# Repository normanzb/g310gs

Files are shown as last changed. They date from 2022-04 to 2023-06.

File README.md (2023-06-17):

# Norm's G310GS mods

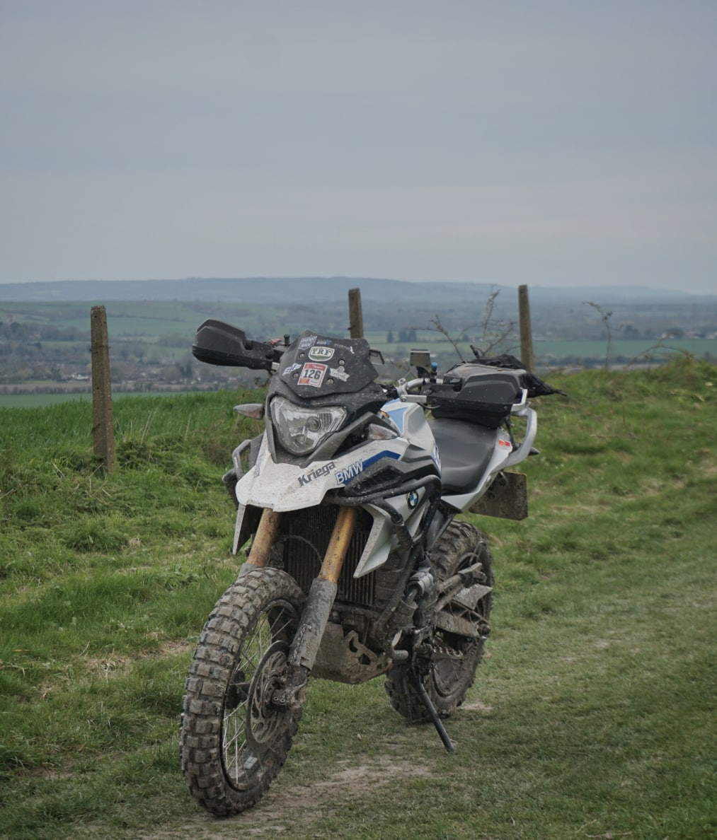
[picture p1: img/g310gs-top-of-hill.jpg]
Norm's G310GS with mods


Second hand G310GS on the market is a lot more affordable and more versatile then a brand new Honda CRF300L, however, when it comes to greenlaning there are improvements to be done to make the baby GS more prepared in the technical terrains.

Here you will find the mods that I made while improving my own g310gs to make it more capable off road.

## Disclaimer: Use at your own discretion

Bike parts can be changed overtime, they can also completely different in shape when it is sold in different region. The part in this repo might not fit straight to your bike.
Authors of this repo do not responsible for any damage caused by the mods made to your property, vehicle or health.

## Mods

--> __[TLDR, straight to the STL files!](https://github.com/normanzb/g310gs/blob/master/release/23_03_24)__ <--

See [changelog](./DocChangelog.md)

### Removing the front mudguard

The baby GS comes with the classic GS beaky look with a lower front mud guard that provides a better high speed riding experience. However in very muddy condition the lower front mud guard can clog up with muds and stop the front wheel from spinning. This makes the bike unrideable until the clearance is re-gained by removing the front mud guard. 

Below parts help you to remove the front mud guard while still providing protection for the vulnerable parts:

* [Radiator guard](./DocRadiatorGuard.md)
* [Fork guards](./DocForkGuards.md)

### Better stand up posture

* [Brake riser](./DocBrakeRiser.md)

## Please Help!

Designing and testing motorbike mods are time consuming and costly, I had to print out the parts, install them on my bike, identify the problems and re-do the design and printing. Each time just the printing along cost me somewhere around £30 to £180. Also in the process I was risking breaking the parts on my bike.

While I am happy to pay for my own habit, if you find this project helpful, please consider donate a little to keep the project going.

__I accept ETH on:__

0xC506739D39cBf1D94E2510bfcA64Cb6015F4Bb1B

__Buy me a drink on paypal:__

https://paypal.me/norx

## Acknowleges

Thanks for user `rcat` from g310rforum.com for the helps and feedbacks.

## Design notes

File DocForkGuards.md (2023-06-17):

# Fork Guards

The latest fork guards are made to fit the rally raid level 2 suspension kit (2mm increase on the total length on the fork). they should work on the stock forks but might be a bit longer then what you wanted.

## Caveats

* For the best result, please use SLS or MDF printer with PA12 Nylon material. 
* For the safety reason, please do check the sign of wear for the brake cable that run through the hoop on the left fork guard.

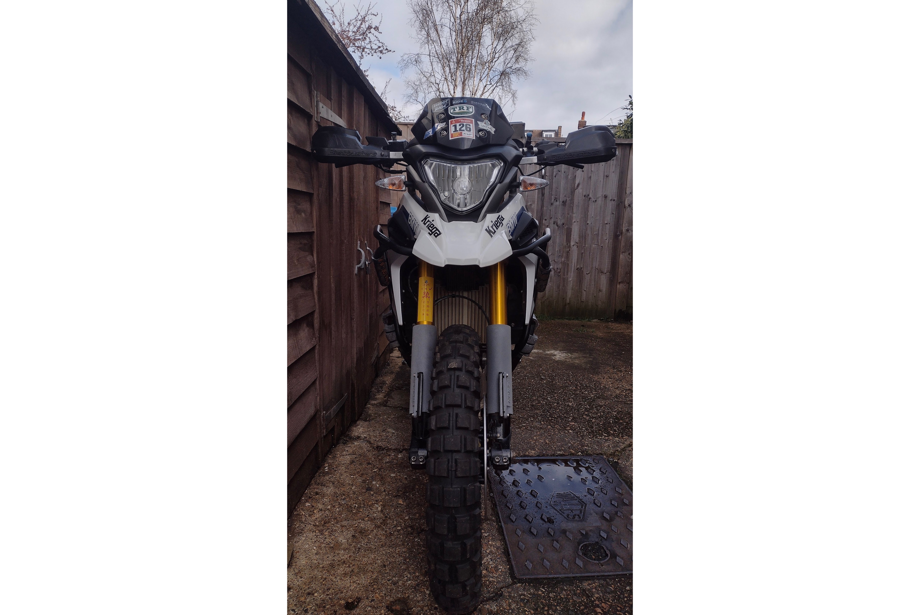
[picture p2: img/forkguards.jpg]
norx fork guards


[Click here for older version that fits stock fork better](https://github.com/normanzb/g310gs/blob/master/release/23_06_17/)

## Rally Raid Lvl2 Right Front Fork Guard

* __Project status:__ Fully Tested
* [STL file preview and download](https://github.com/normanzb/g310gs/blob/master/release/23_03_20/mudguard_alt_right_rally_raid_lvl2.stl)

## Rally Raid Lvl2 Left Front Fork Guard

* __Project status:__ Fully Tested
* [STL file preview and download](https://github.com/normanzb/g310gs/blob/master/release/23_06_17/mudguard_alt_left_rally_raid_lvl2.stl)

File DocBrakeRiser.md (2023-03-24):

# Brake riser

It comes with 2 variants: 15mm and 25mm. Both comes with holes that fits 3mm grub screws, so you can further micro adjusting the position by fitting longer or shorter grub screws.

To secure it to the original brake pedal, use 4 2mm wide zipties and route them through horizontal securing holes on the riser.

## Brake riser 15mm

* __Project status:__ Old version fully tested, ziptie version hasn't
* [STL file preview and download](https://github.com/normanzb/g310gs/blob/master/release/23_03_24/brake_riser_15mm_ziptie.stl)

15mm version works the best with sw motech footpegs in low position.

## Brake riser 25mm

* __Project status:__ Old version fully tested, ziptie version hasn't
* [STL file preview and download](https://github.com/normanzb/g310gs/blob/master/release/23_03_24/brake_riser_25mm_ziptie.stl)

25mm version works the best with fastway footpegs.

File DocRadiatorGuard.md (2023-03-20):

## Radiator Guard

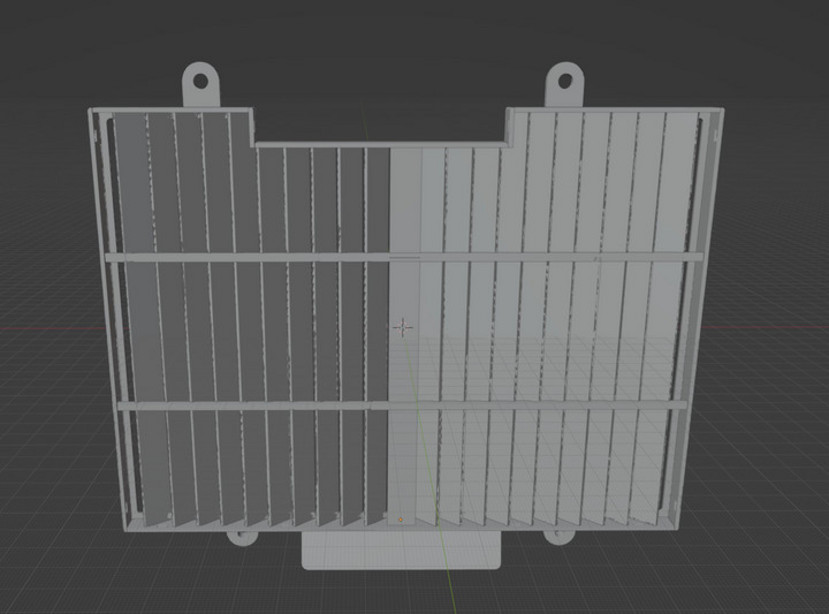
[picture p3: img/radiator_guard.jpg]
Radiator guard


* __Project status:__ Prototype Tested
* __Printing Caveat:__ Use heat resistent material
* [STL file preview and download](https://github.com/normanzb/g310gs/blob/master/release/23_03_20/radiator%20guard.stl)

What prevents most people front removing the front mud guard is the rocks or sand blasting from the front wheel can damage the radiator fins. And all the after market radiator guards you can buy are just a thin layer of metal that only protect against small rocks but still allowing the sand particles to go through.

If you look carefully, almost all the off road oriented bikes, including all the MX/enduro bikes and KTM 890 ADV and yamaha tenere 700, they all come equiped a stock radiator guard that consist of a series louvre blades. These blades not only protect against rocks but also sand blasting.

Below are few examples:

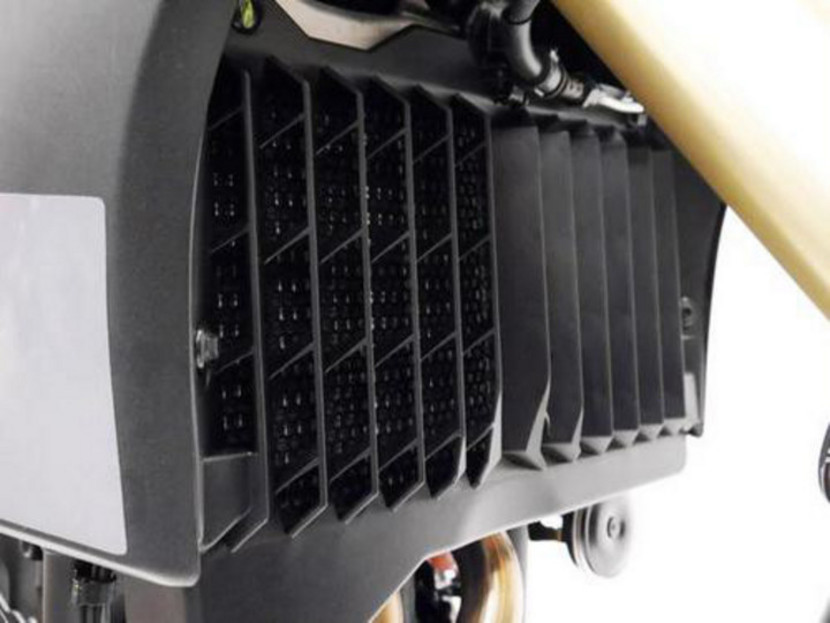
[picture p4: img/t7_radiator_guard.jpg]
Stock Radiator Guard on tenere 700


_Stock Radiator Guard on tenere 700_

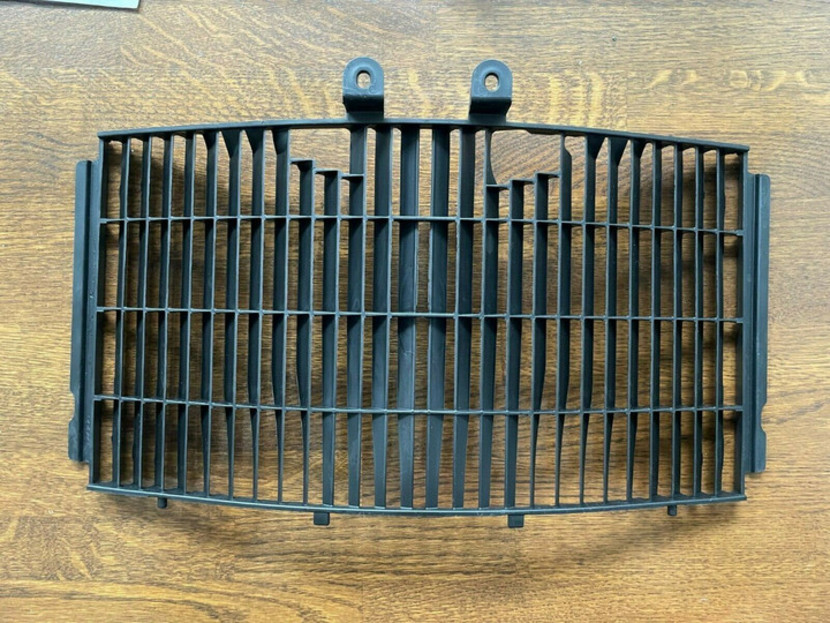
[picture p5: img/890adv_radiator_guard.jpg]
Stock Radiator Guard on KTM 890 adv


_Stock Radiator Guard on KTM 890 adv_

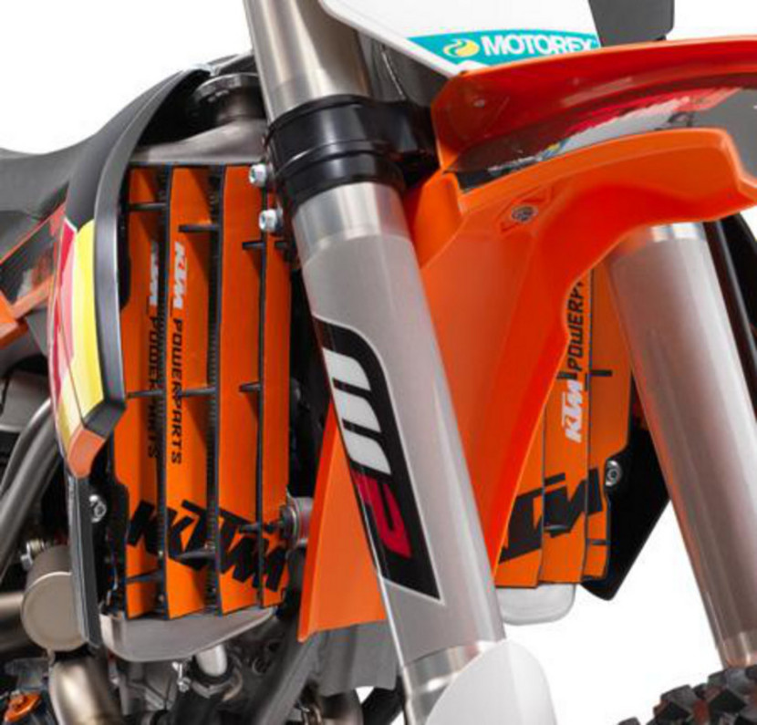
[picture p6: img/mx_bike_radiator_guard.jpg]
Almost all MX bikes have fitted with louvre blades


_Almost all MX bikes have fitted with louvre blades_

Our radiator guard tries to achieve the same by adding the louvre blades, you can also secure a piece of drain grill mesh on top of it with a ziptie to add some more protection against rocks.

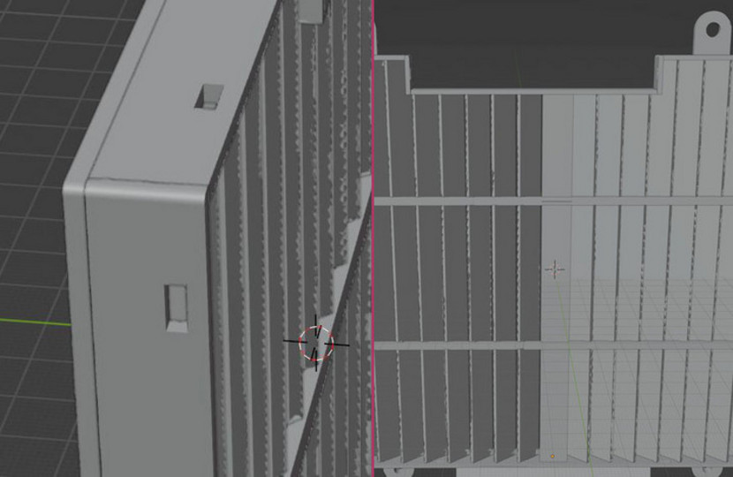
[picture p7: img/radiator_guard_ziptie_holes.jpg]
Radiator guard ziptie holes


_We added holes on the radiator guard so that you can secure a piece of drain grill mesh with a ziptie on it_

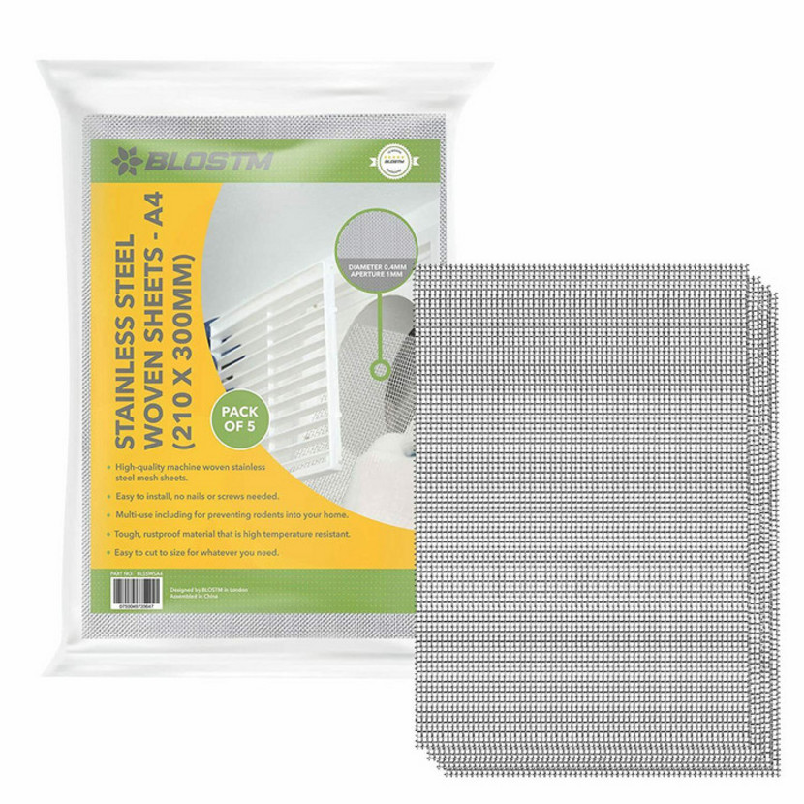
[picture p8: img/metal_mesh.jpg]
Metal mesh


_You can fit metal mesh from ebay to add some more protection_

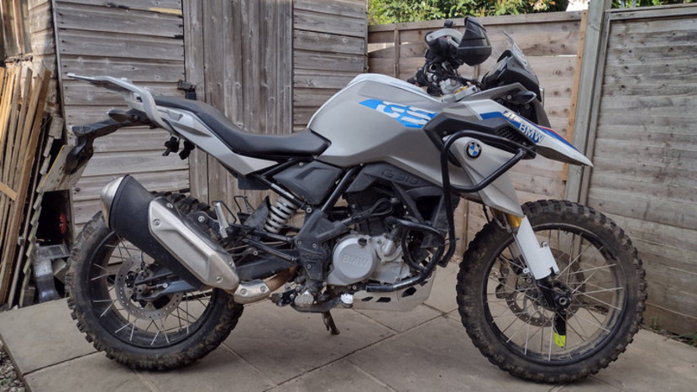
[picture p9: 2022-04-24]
img/g310gs_with_mods.jpg

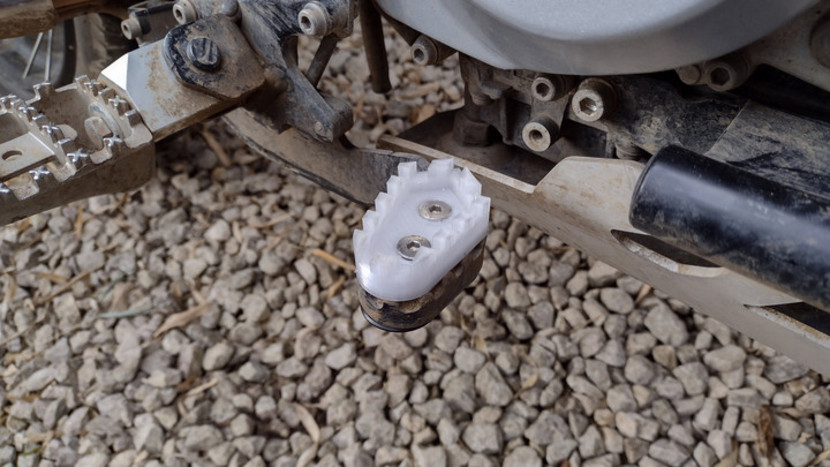
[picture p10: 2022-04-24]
img/brake_riser.jpg

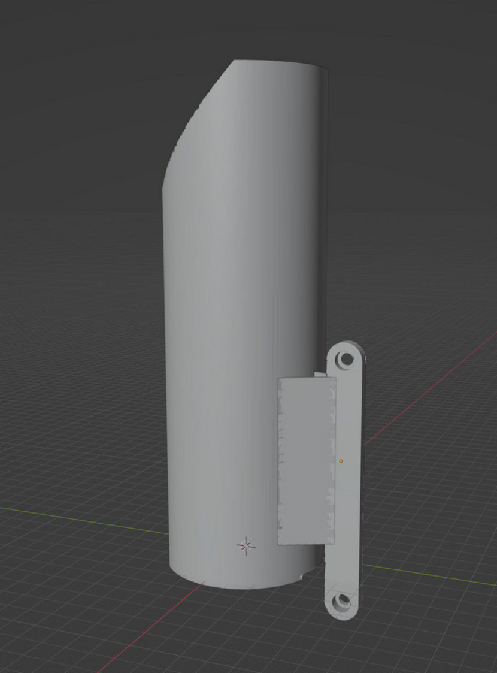
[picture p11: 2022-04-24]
img/mud_guard_right.jpg

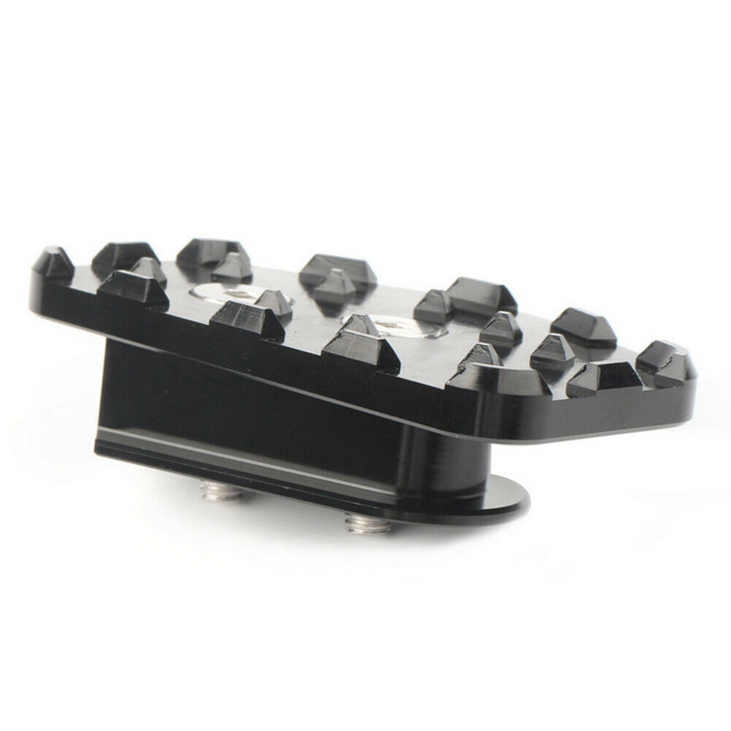
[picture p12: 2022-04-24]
img/ebay_brake_extension.jpg

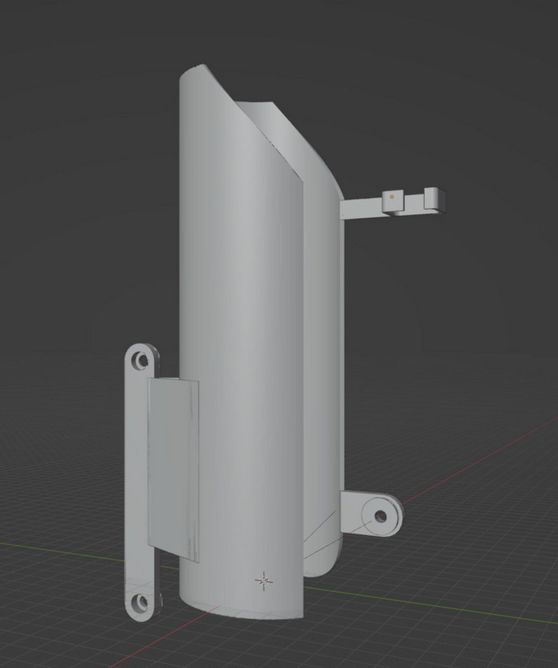
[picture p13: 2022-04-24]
img/mud_guard_left.jpg

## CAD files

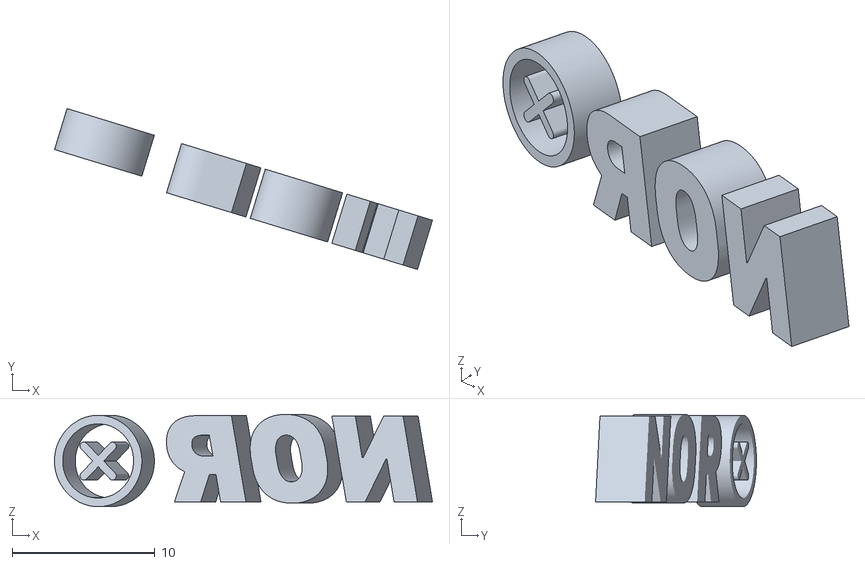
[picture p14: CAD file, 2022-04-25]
norx.stl
26.5 x 11.3 x 6.46

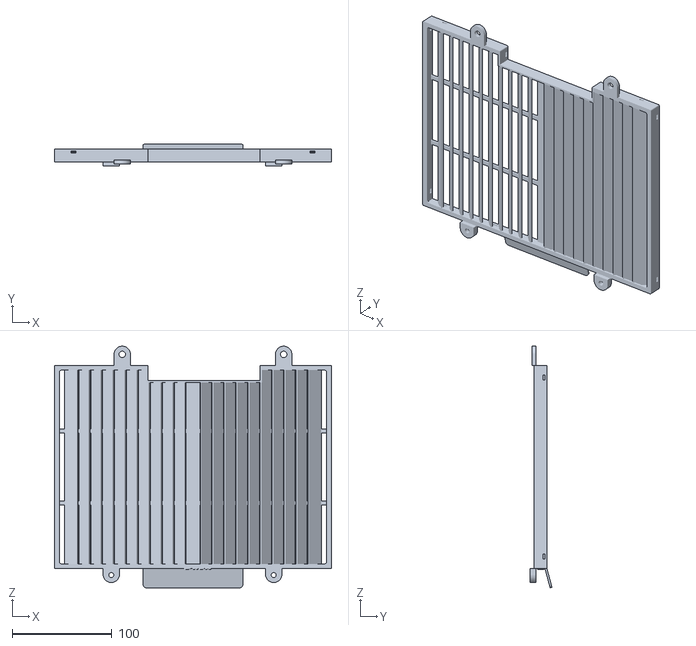
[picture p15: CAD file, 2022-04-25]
release/22_04_25/radiator guard.stl
278.0 x 22.1 x 242.5

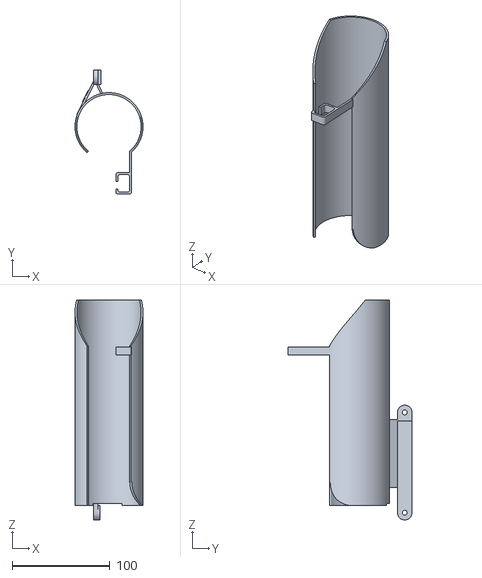
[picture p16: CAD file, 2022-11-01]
release/22_11_01/mudguard alt left.stl
69.6 x 127.0 x 225.0

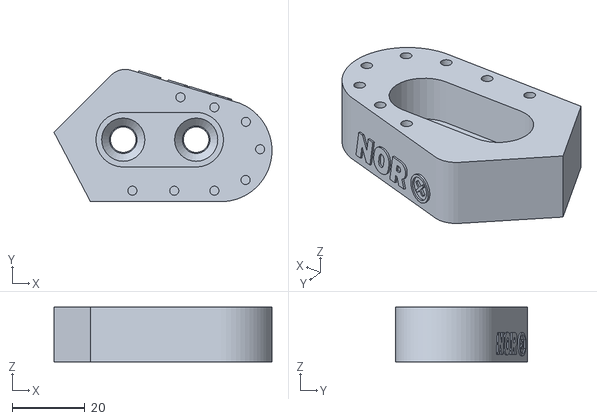
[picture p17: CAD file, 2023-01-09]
release/23_01_09/brake_riser.stl
59.8 x 36.3 x 15.0

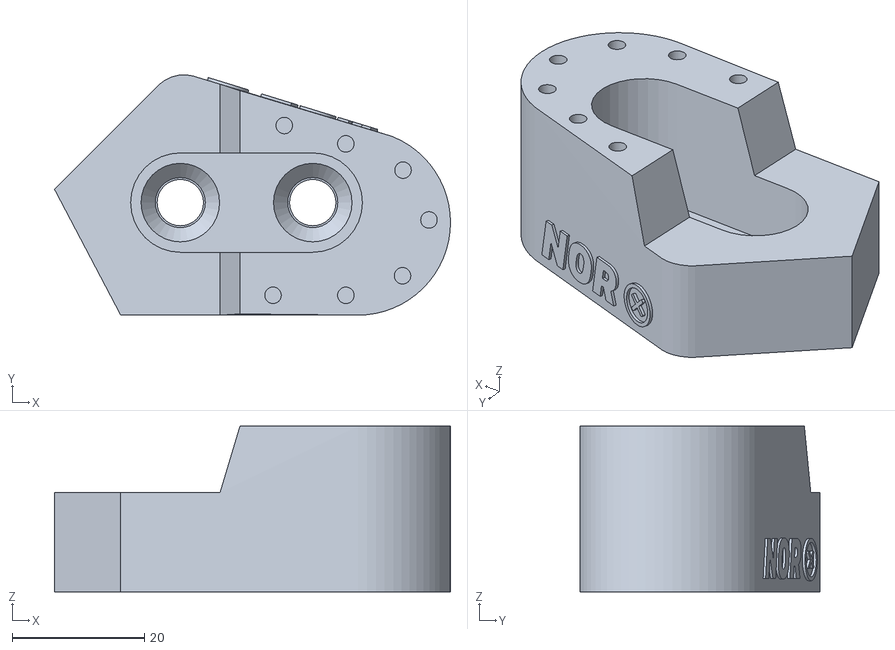
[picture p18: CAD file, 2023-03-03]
release/23_02_28/brake_riser_25mm.stl
59.8 x 36.3 x 25.0

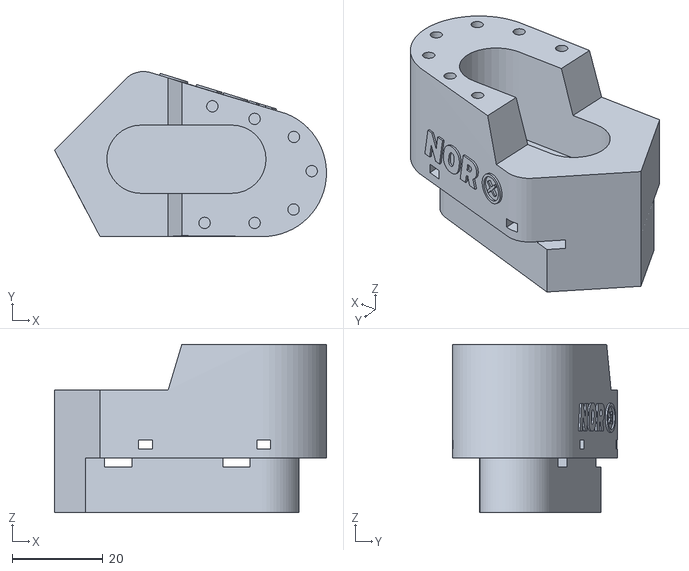
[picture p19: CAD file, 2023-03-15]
release/23_03_13/brake_riser_25mm_ziptie.stl
59.8 x 36.3 x 37.0

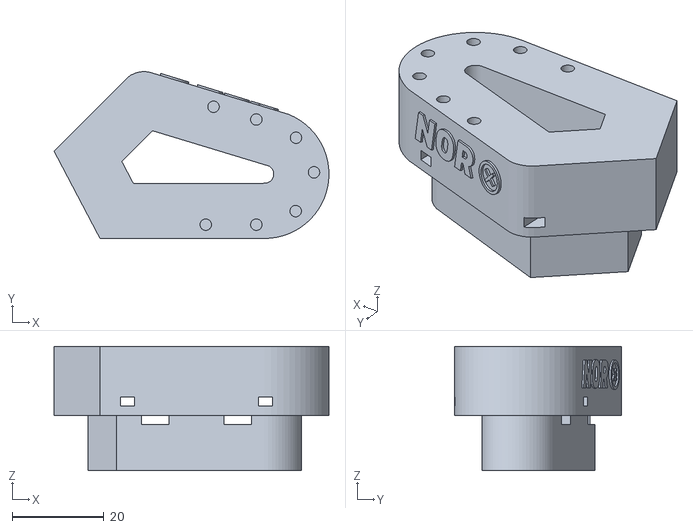
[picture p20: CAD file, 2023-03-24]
release/23_03_24/brake_riser_15mm_ziptie.stl
59.8 x 36.3 x 27.0

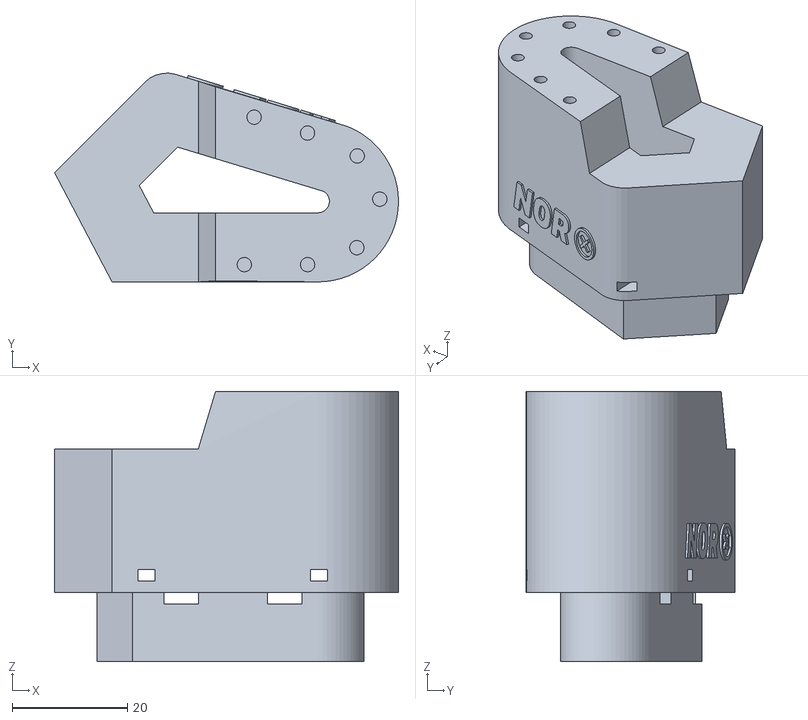
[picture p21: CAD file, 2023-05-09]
release/23_05_09/brake_riser_35mm_ziptie.stl
59.8 x 36.3 x 47.0

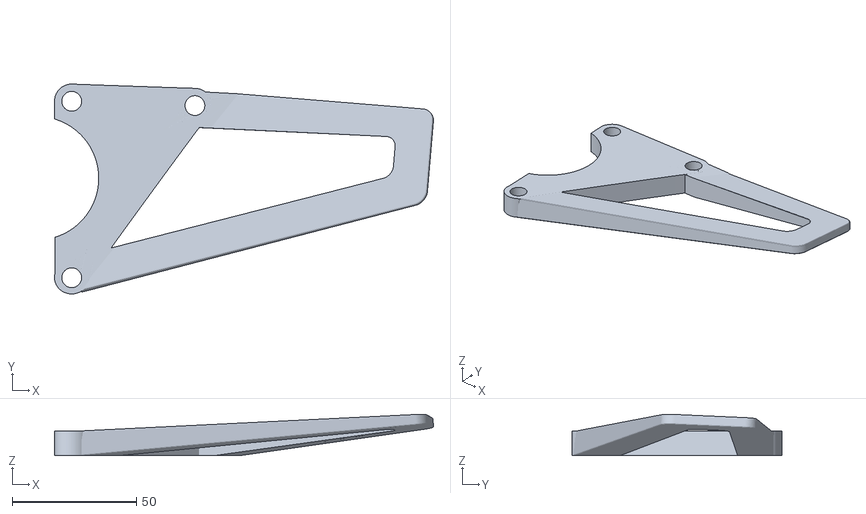
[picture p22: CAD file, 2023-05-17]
release/23_05_17/pillion_pegs_rack_replacement.stl
152.5 x 84.5 x 16.6

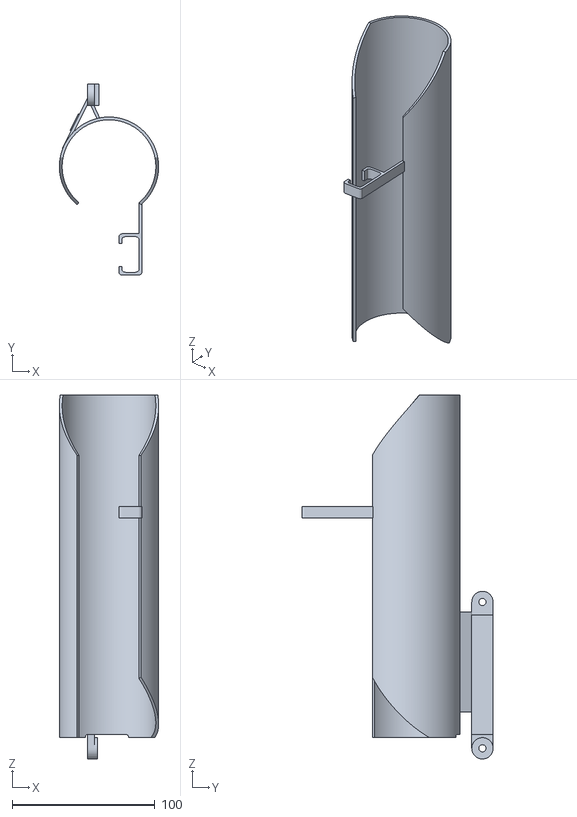
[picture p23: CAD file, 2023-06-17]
release/23_06_17/mudguard_alt_left_rally_raid_lvl2.stl
69.6 x 134.0 x 255.0

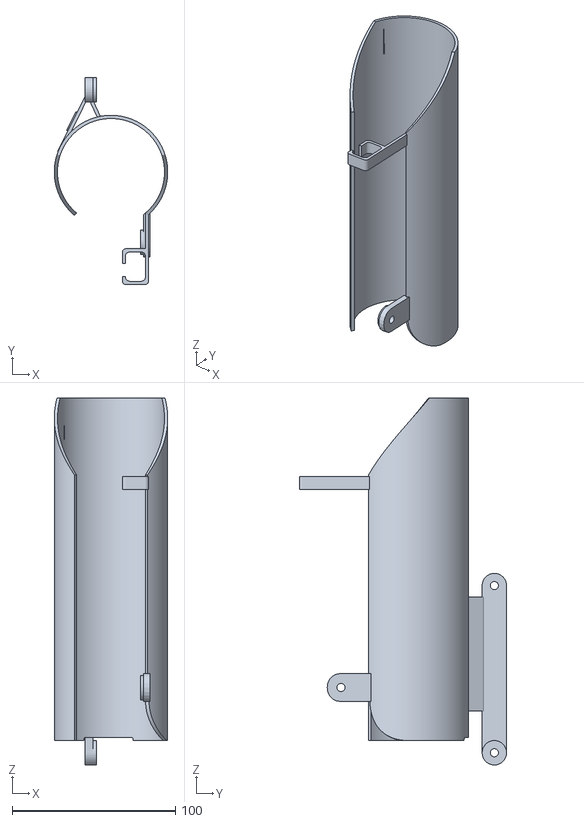
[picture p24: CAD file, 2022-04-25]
release/22_04_25/mudguard alt left.stl
69.6 x 127.0 x 225.0

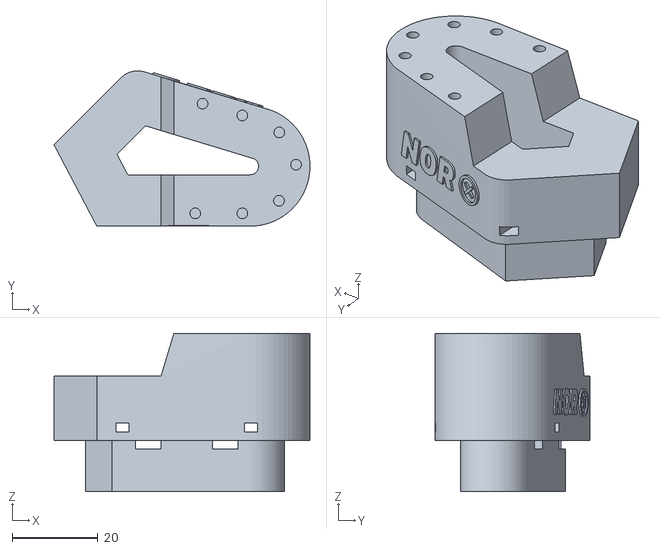
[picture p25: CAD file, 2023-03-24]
release/23_03_24/brake_riser_25mm_ziptie.stl
59.8 x 36.3 x 37.0

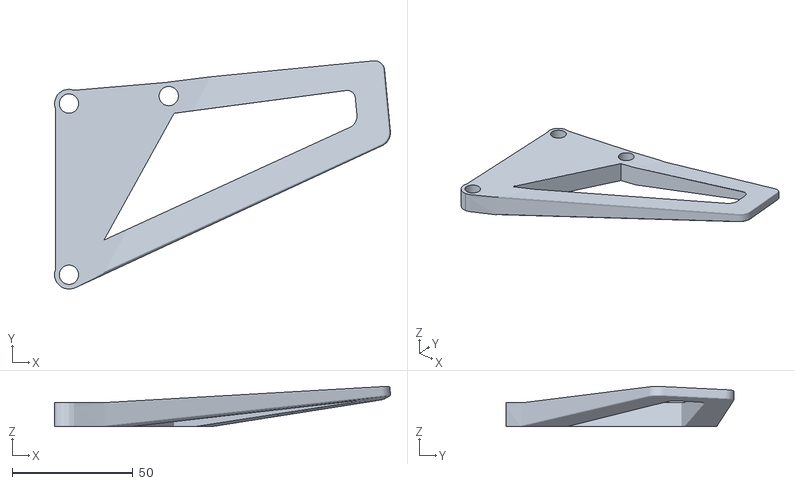
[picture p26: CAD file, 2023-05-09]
release/23_05_09/pillion_pegs_rack_replacement_left.stl
139.4 x 94.8 x 16.6

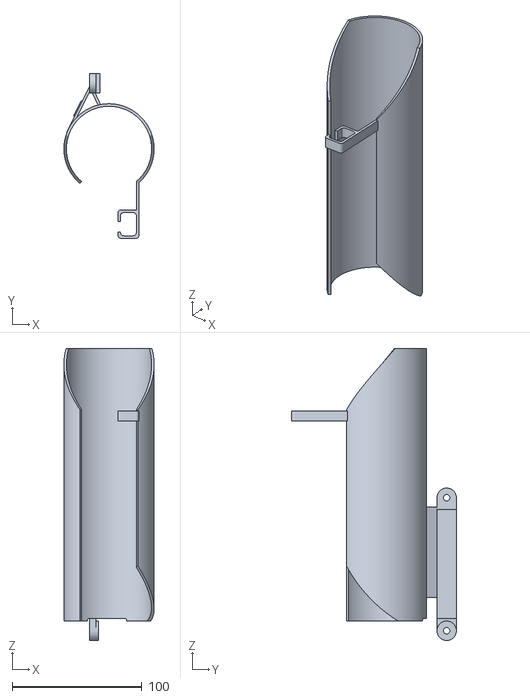
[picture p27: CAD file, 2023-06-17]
release/23_06_17/mudguard_alt_left.stl
69.6 x 127.0 x 225.0

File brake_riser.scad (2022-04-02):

// polygon([[0, 0], [135, 0], [8, 37],  [-10, 19]]);


union() {    
    polygon(
        [[0, 0], [36, 0], [41, 27],  [13, 35], [2, 31.5], [-10, 19]]
    );
    translate([35.5, 14, 0]) {
        circle(14);
    }
}



// rotate_extrude(convexity = 1)
// translate([2, 0, 0])
// circle(r = 1, $fn = 100);

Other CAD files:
release/22_04_25/mudguard alt right.stl
release/23_03_24/radiator guard.stl
release/23_06_17/mudguard alt right.stl
release/22_04_25/brake riser.stl
brake_riser_15mm.blend
brake_riser_25mm.blend
brake_riser_25mm_ziptie.blend
mudguard_alt_left.blend
mudguard_alt_left_rally_raid_lvl2.blend
mudguard_alt_right.blend
mudguard_alt_right_rally_raid_lvl2.blend
pillion_pegs_rack_replacement.blend
radiator guard.blend
release/21_12_01/mudguard alt left.stl
release/21_12_01/mudguard alt right.stl
release/21_12_01/radiator guard.stl
release/22_01_01/mudguard alt left.stl
release/22_01_01/mudguard alt right.stl
release/22_01_01/radiator guard.stl
release/22_04_02/brake riser.stl
release/22_04_02/mudguard alt left.stl
release/22_04_02/mudguard alt right.stl
release/22_04_24/brake riser.stl
release/22_04_24/mudguard alt left.stl
release/22_04_24/mudguard alt right.stl
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

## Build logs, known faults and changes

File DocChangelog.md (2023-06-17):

## 23-06-17

1. based on feedback from user `rcat` from g310rforum, moved 1mm inward on the front bracket for the left fork guard.
2. based on feedback from user `rcat` from g310rforum, increased the size of cut off for abs rack.

## 23-03-24

1. add a bigger vertical hollow to the brake riser so we can route ziptie through the hollow to better secure the brake riser

## 23-03-22

1. fixed brake riser geometry issue that prevent it from be inserted into brake pedal.
2. added a hole to brake riser for water escape.
3. readjust ziptie strap locations due to issues above.

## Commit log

2022-02-16 upload belnder files\
    [mudguard alt left.blend, mudguard alt left.stl, mudguard alt right.blend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]
2022-04-02 add brake riser
    [brake riser.blend, brake riser.scad, brake riser.stl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]
2022-04-02 brake riser
    [mudguard alt left.stl]
2022-04-24 updated riser file
    [brake riser.stl]
2022-04-24 brake riser should be final now
    [brake riser.blend]
2022-04-24 adjust mudguard right because too tight on the right side
    [mudguard alt right.blend]
2022-04-24 enlarge mudguard alt cable hook for stronger and better protection
    [mudguard alt left.blend]
2022-04-24 move release files into release folder
    [brake riser.stl, mudguard alt left.stl, mudguard alt right.stl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]
2022-04-24 rename release folder for easier sorting
    [brake riser.stl, mudguard alt left.stl, mudguard alt right.stl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]
2022-04-24 release: 22_04_24
    [brake riser.stl, mudguard alt left.blend, mudguard alt left.stl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]
2022-04-24 release the radiator guard as well
    [radiator guard.stl]
2022-04-24 hide rear bracket and re-release
    [mudguard alt right.blend, mudguard alt right.stl]
2022-04-24 fix a tear caused by not enough of viewport for subdivision
    [mudguard alt right.blend, mudguard alt right.stl]
2022-04-24 fix another tearing issue caused by subdivsiion
    [mudguard alt right.blend, mudguard alt right.stl]
2022-04-25 add logo
    [brake riser.blend, brake riser.stl, norx.stl]
2022-04-25 add logo to right mudguard
    [mudguard alt right.blend, mudguard alt right.stl]
2022-04-25 release 22_04_25: add logo to all files
    [mudguard alt left.blend, mudguard alt left.stl, radiator guard.blend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]
2022-11-01 increase thickness of front bracket to avoid breakage
    [mudguard alt left.blend, mudguard alt left.stl, mudguard alt right.blend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]
2022-11-01 fix a rendering issue
    [mudguard alt left.blend, mudguard alt left.stl]
2023-01-09 add support for rally raid lvl2 suspension, change brake riser to use grub screws
    [brake riser.blend, mudguard alt left rally raid lvl2.blend, mudguard alt right rally raid lvl2.blend]
2023-01-09 rename files
    [brake_riser.blend, brake_riser.scad, mudguard_alt_left.blend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]
2023-01-09 release 23_01_09
    [brake_riser.stl, mudguard_alt_left_rally_raid_lvl2.stl, mudguard_alt_right_rally_raid_lvl2.stl]
2023-01-22 avoid wear because of touching with cable and bracket
    [mudguard_alt_left_rally_raid_lvl2.blend]
2023-02-28 add new 25mm riser
    [brake_riser_15mm.blend, brake_riser_25mm.blend]
2023-03-03 release higher riser
    [brake_riser_25mm.stl]
2023-03-10 radiator guard remove bottom fairing
    [radiator guard.blend, radiator guard.stl]
2023-03-13 experiementing with ziptie secured version of riser
    [brake_riser_15mm_ziptie.stl, brake_riser_25mm_ziptie.blend, brake_riser_25mm_ziptie.stl]
2023-03-15 add new brake riser design
    [brake_riser_25mm_ziptie.stl]
2023-03-20 release latest changes
    [brake_riser_15mm_ziptie.stl, brake_riser_25mm_ziptie.blend, brake_riser_25mm_ziptie.stl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]
2023-03-22 release new changes to brake riser
    [brake_riser_15mm_ziptie.stl, brake_riser_25mm_ziptie.blend, brake_riser_25mm_ziptie.stl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]
2023-03-24 release 23_03_24
    [brake_riser_15mm_ziptie.stl, brake_riser_25mm_ziptie.blend, brake_riser_25mm_ziptie.stl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]
2023-05-09 add 35mm brake riser and rack replacement
    [brake_riser_25mm_ziptie.blend, brake_riser_35mm_ziptie.stl, pillion_pegs_rack_replacement.blend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]
2023-05-17 upload new test stl
    [pillion_pegs_rack_replacement.stl]
2023-06-17 update 23-06-17 according to user `rcat` fro g310rforum
    [mudguard alt right.stl, mudguard_alt_left.stl, mudguard_alt_left_rally_raid_lvl2.stl]
2023-06-17 fix blender render issue
    [mudguard_alt_left.stl, mudguard_alt_left_rally_raid_lvl2.stl]
